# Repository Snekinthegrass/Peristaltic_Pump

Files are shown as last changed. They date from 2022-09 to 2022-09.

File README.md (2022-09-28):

# Peristaltic_Pump

# **MOTOR SHAFT IN THIS DESIGN IS 10MM**

# Build Notes
If your motor has a different shaft diameter(it probably does) please modify .f3d accordingly before printing rotor

Designed for A nema 23 stepper motor with a 10x20mm shaft 

All M5 Screws are socket head type.

Designed for printing the rotor and rollers on Saturn SLA resin printer but a well tuned fdm printer should do it, though post processing is likely going to be needed either way.

The 625 bearings should slide into the rollers without force, they should be snug but not forced, they will break if they are forced into a hole that is too small for them and forced to rotate
2/3rds of my bearings are now crunchy :>

It is worth smoothing down any sharp edges left over from the printing process anywhere where the silicone tube comes into contact with the printed parts. 

May be worth using super glue to permentaly set the nuts on the bottom halfshell when I pulled them into the cover they deformed the pla and spun in place. 

M5 Screws securing the halfshells togther should be able to be inserted all the way to the nut without interfacing with the plastic, if they do drill or file to the correct size before securing hose in place. 

Only tested with a 4.2A 3NM Stepper motor I'd assume they'll be fine but it remains untested.

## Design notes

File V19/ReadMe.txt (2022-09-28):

<============================================>
<============Bill of Materials===============>
<============================================>
A): 5 M5x30mm          (Rotor->Roller)
B): 4 M5x40mm          (Cover -> Pump Body)
C): 4 M5x10mm          (Pump Body -> Nema23,  May require a washer between pump and stepper. Screw ends should be flush
D): 2 M5x30mm          (SetScrews)
E): 15 M5 nuts
F): 10 625-2RS Bearing (Roter -> rollers)
G): 9mm ID x 12mm OD silcone tubing (length is up to your judgment)
H): 1 Nema23 stepper with 10mm shaft 
I): 1 Stepper Driver spec'd to your motor
J): Printed Parts
	1): 1x Pump Housing Top
	2): 1x Pump Housing Bottom
	3): 1x Rotor
	4): 5x Rollers

<============================================>
<============Basic Instructions==============>
<============================================>

->Set M5 nuts into bottom half shell use screw to pull them into the plastic, use a longer screw than need so if nuts deform plastic and spin in place you can push them out. 

->Set M5 Nuts into rotor same process as bottom halfshell. 

->Assemble rotor with rollers 
Insert 625 bearings into rollers, they should be able to be insert with very little effort and be able to be removed with out forcing them. 
Don't try to force bearings to fit they may go but they'll get crunchy quickly, like 2/3rds of my bearings are now :<

-> Insert rollers with bearings into the rotor and secure with m5x30 and nut, they don't need to be very tight just enough so they won't back out, blue locktight may help.

-> Attach bottom halfshell to stepper with M5x10 I had to use washers between motor and shell and a set of m5 nuts between top of the screw and the motor to ensure screws do not protrude to far, they should end up flush.

-> Insert assembled rotor assembly onto the motor shaft take care to get the placement correct the set screw hole should be just about inline with the tool access hole(the nose of the face).

-> Insert tubing, helps to turn the rotor, get the tube down about halfway between body and rollers. 

-> Carefully tighten down the top halfshell making sure not to pinch the tubing, the housing don't need to be torqued down real tight get them flush and once you test run the motor back off enough the motor runs smoothly.

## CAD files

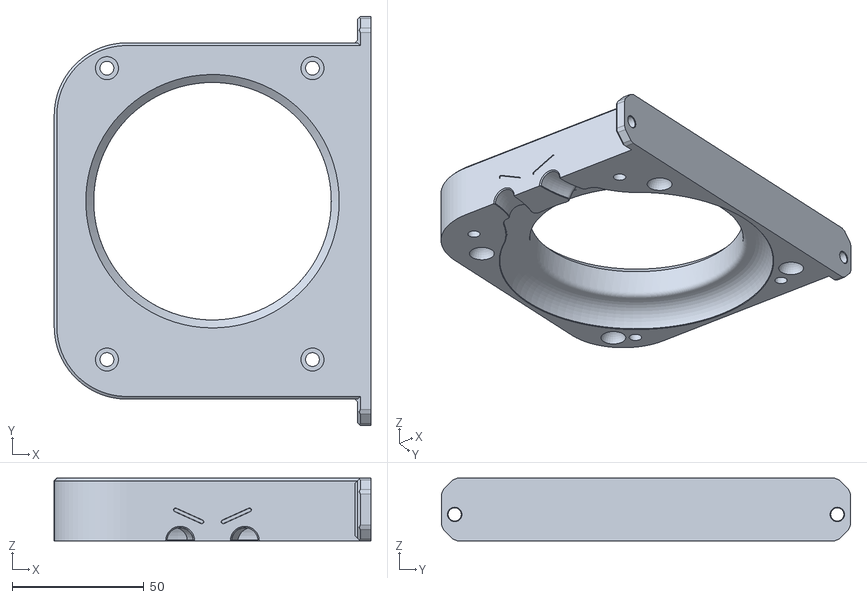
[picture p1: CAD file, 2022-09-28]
V19/Top.stl
120.0 x 155.0 x 23.8

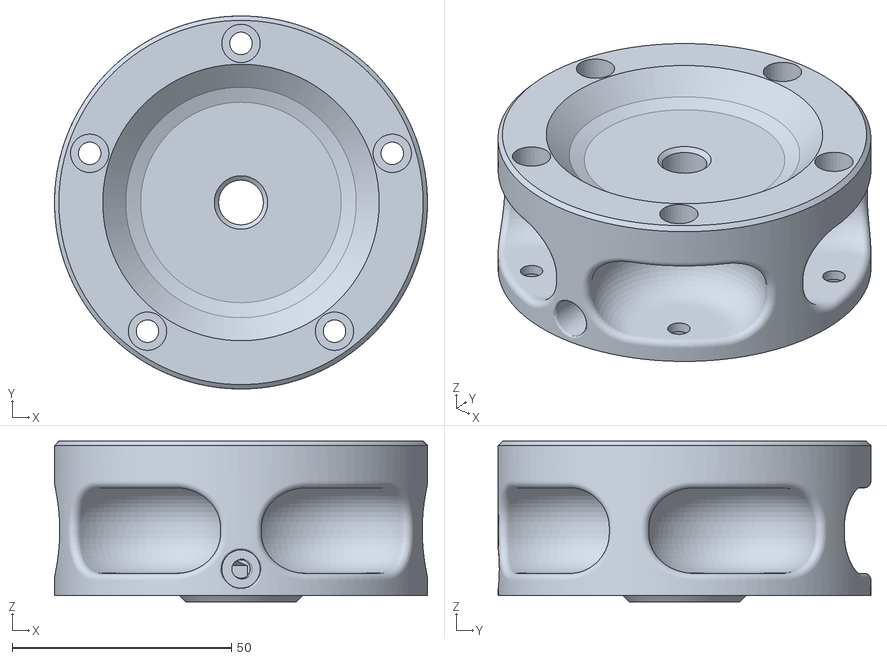
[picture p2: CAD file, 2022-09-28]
V19/Rotor.stl
85.0 x 85.0 x 36.7

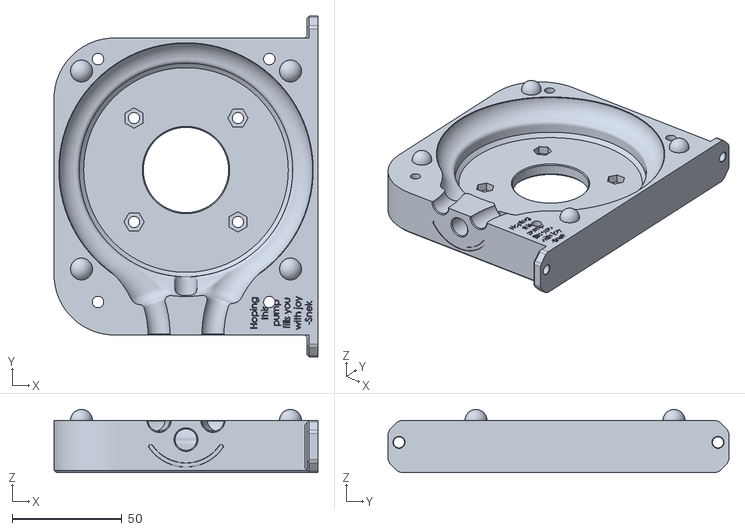
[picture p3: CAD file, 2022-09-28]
V19/Bottom.stl
120.0 x 155.0 x 28.8

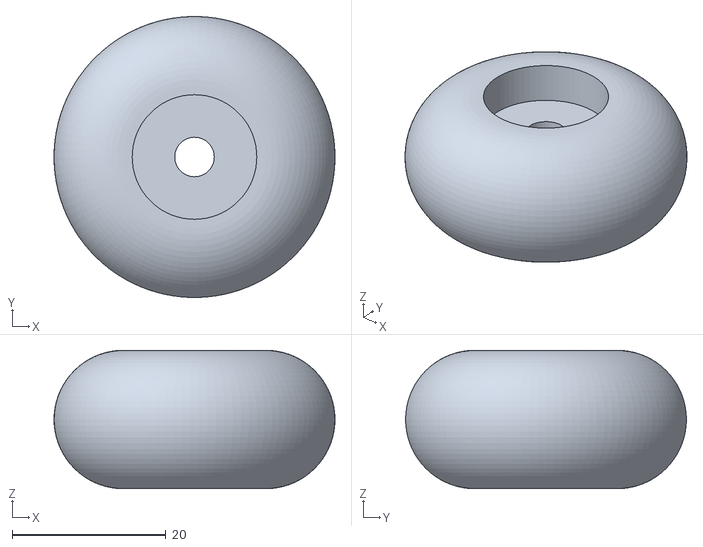
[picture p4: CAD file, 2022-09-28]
V19/Roller.stl
36.5 x 36.5 x 18.0

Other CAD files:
V19/Peristaltic Pump v19.f3d
